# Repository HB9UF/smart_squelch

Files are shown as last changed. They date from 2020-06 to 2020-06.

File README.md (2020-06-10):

HB9UF Smart Squelch -- A squelch board with clever logic
========================================================

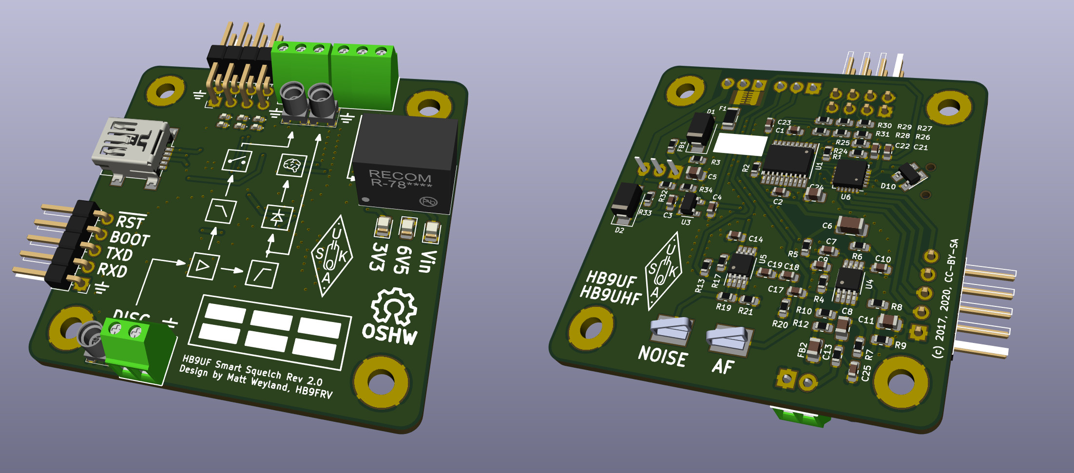
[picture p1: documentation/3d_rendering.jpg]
3D Rendering


A typical FM squelch for voice operation quantifies the amount of noise at frequencies above the voice frequency content and opens if said noise energy is sufficiently low. This works because without any input RF signal present, the FM detector produces wideband noise, reaching frequencies of several dozen kHz. A sufficiently strong RF input reduces that noise, the modulation emerges between typically 0 and 3 kHz and similarly, the noise above 3 kHz is reduced. Traditionally, a high-pass filter (HPF) attenuates the modulation while retaining the noise energy, and a subsequent peak-detector quantifies the amount of energy present, and finally a comparator circuit uses the peak detector output voltage to actuate the squelch.

Our squelch circuit is different. First, we use a microcontroller for the squelch logic. This allows us not only to change squelch thresholds without hardware access, but we can also implement more sophisticated squelching logic. For example, we can implement a hard threshold that is used when strong stations key off: The squelch is closed immediately, minimizing the squelch crash that is nothing but the manifestation of discriminator noise during the time-window after key-off and the closing of the squelch. At the same time, we can implement a second threshold for weak stations, e.g. stations far away, with low RF power, fading stations, or mobile stations with picket-fencing. Such stations may overcome the weak, but not the strong threshold. In this case, the squelch remains open for a predetermined time-window (e.g. 1 second) in order not to cut off the weak station. Note that this is superior to simply adding hysteresis to the aforementioned comparator, and that this is mimicking the behaviour of the [MICOR Squelch](http://www.repeater-builder.com/micor/micor-bi-level-squelch-theory.html) system.

The board also contains a number of extra circuitry such as an anti-aliasing low pass filter, a DC/DC converter etc. for integration with our repeater controller. This project is fully open source, the hardware is released under the CC-BY-SA license and the firmware is released under the GPL 2 license. Instructions for compiling and flashing the firmware are documented in a `README` file in the `firmware` subdirectory. The necessary tools and frameworks (ChibiOS and stm32flash) are also included there as git submodules. The circuitry was developed to improve the poor squelch performance of the Yaesu DR-1X repeater and is also successfully used in a number of homebrew 1.3 GHz repeaters.

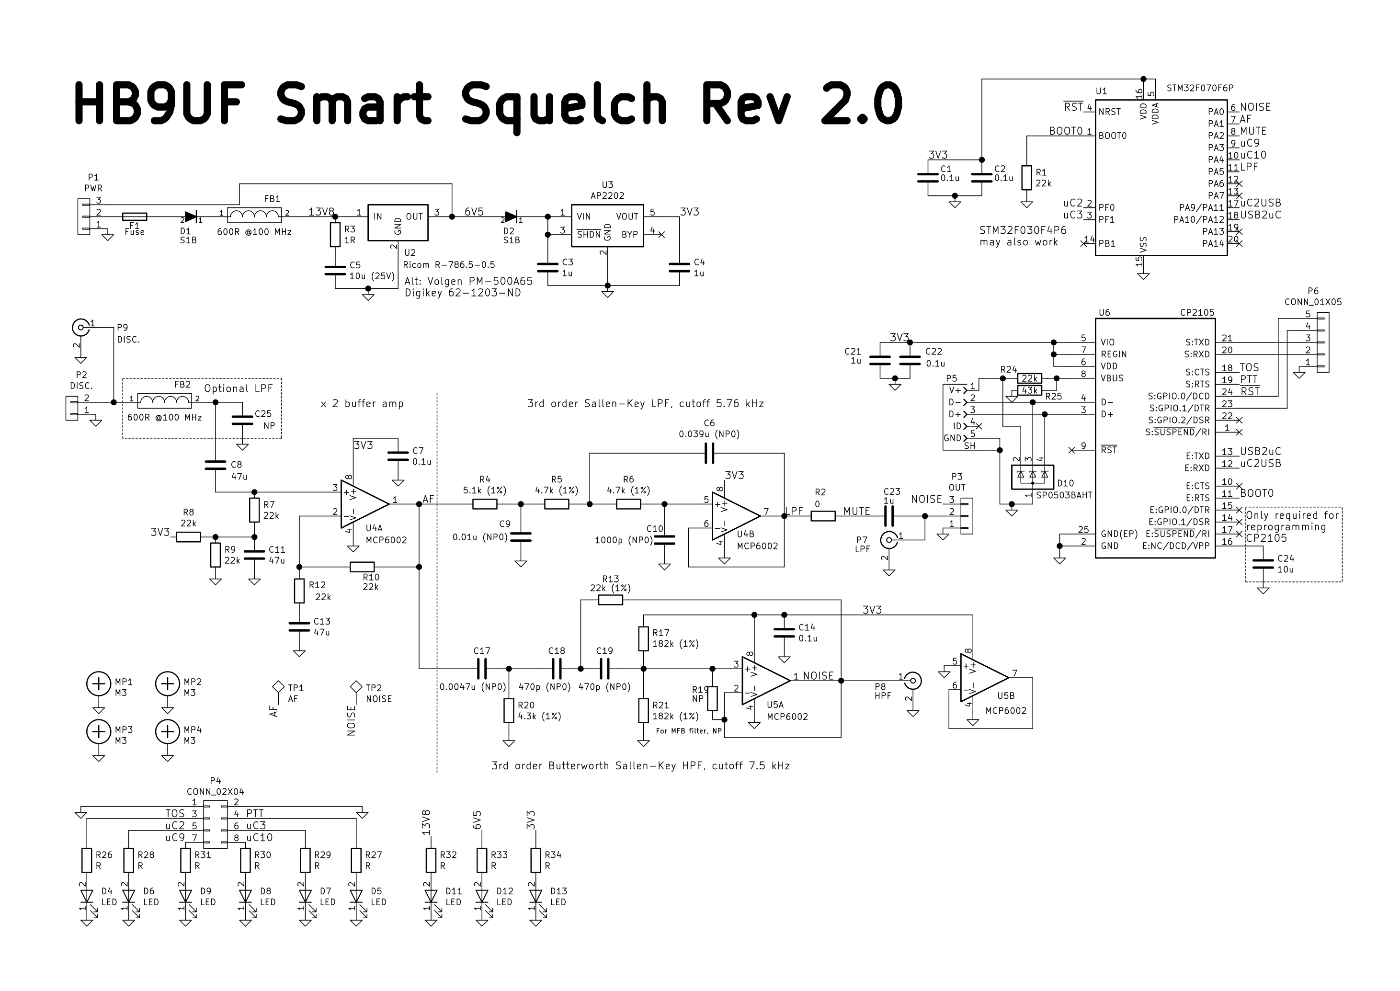
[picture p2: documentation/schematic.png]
Schematic


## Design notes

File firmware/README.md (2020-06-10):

Compiling
=========

This is how to compile the firmware on linux:

1. Check out the ChibiOS submodule by running `git submodule update --init`. Alternatively, modify the Makefile to point to your existing ChibiOS root.
2. Run the `make`command.
3. Firmware is available in the `build` subdirectory.

Programming
===========

The STM32 microcontroller can be flashed from USB using the 'stm32flash-code' tool. The microcontroller needs to boot into the bootloader for this to work. Follow these steps in order to achieve this:

1. Activate the GPIO capabilities of the CP2105 USB bridge: `echo 355 > /sys/class/gpio/export`. The Number (355) may vary on your system.
2. Reset the microcontroller. The BOOT0 pin is high by default, starting the bootloader in reset:
```
echo 0 > /sys/class/gpio/gpio355/value
sleep 0.1
echo 1 > /sys/class/gpio/gpio355/value
```
3. Flash the firmware: `stm32flash -w build/ch.hex /dev/ttyUSB0`
4. Pull the BOOT0 pin low. The pin is connected to the RTS. Helper program rts.py keeps the pin low for 10 seconds. Thus, running `python rts.py &` fulfils this step. The subsequent reset in the next step must take place within 10 secods.
5. Reset the microontroller once again:
```
echo 0 > /sys/class/gpio/gpio355/value
sleep 0.1
echo 1 > /sys/class/gpio/gpio355/value
```

Alternatively, `stm32flash` can be alled with the appropriate entry and exit sequences:

```
stm32flash-code/stm32flash -w ../firmware/build/ch.hex /dev/ttyUSB0 -i '-rts,-355,355,,,:rts,-355,355'
```

Note that this still requires activation of the P2105 GPIO capabilities and the GPIO number (355) is subject to change.

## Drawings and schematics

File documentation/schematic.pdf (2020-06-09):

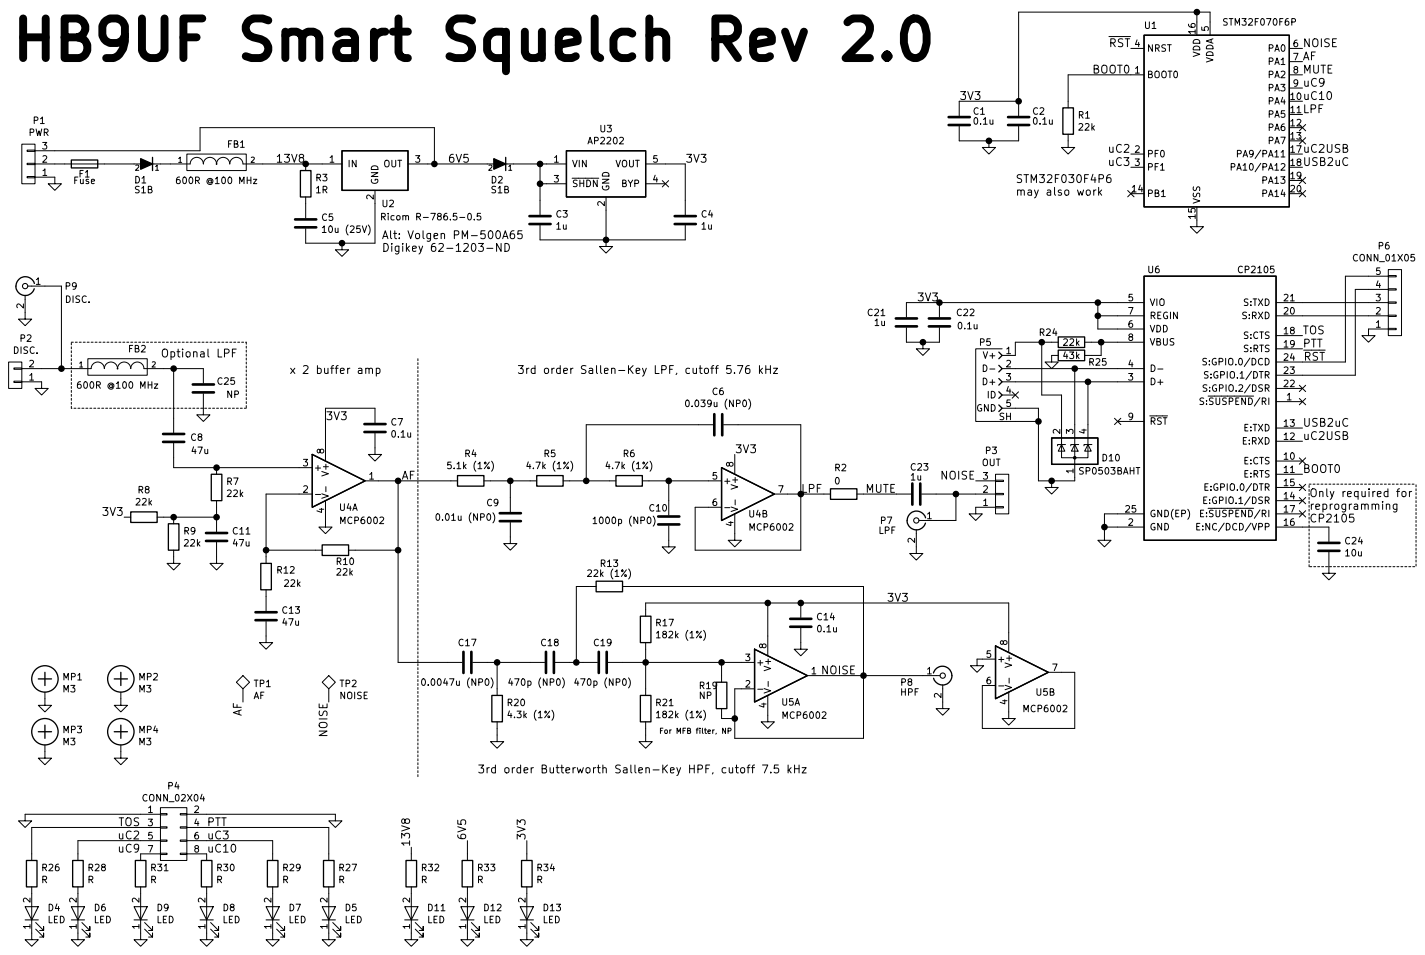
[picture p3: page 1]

may also work Todo: - output divider

For MFB filter, NP HB9UF Smart Squelch Rev 2.0

3rd order Butterworth Sallen-Key HPF, cutoff 7.5 kHz

TOS 3 | 4 PTT
uC2 5 | uC3 6

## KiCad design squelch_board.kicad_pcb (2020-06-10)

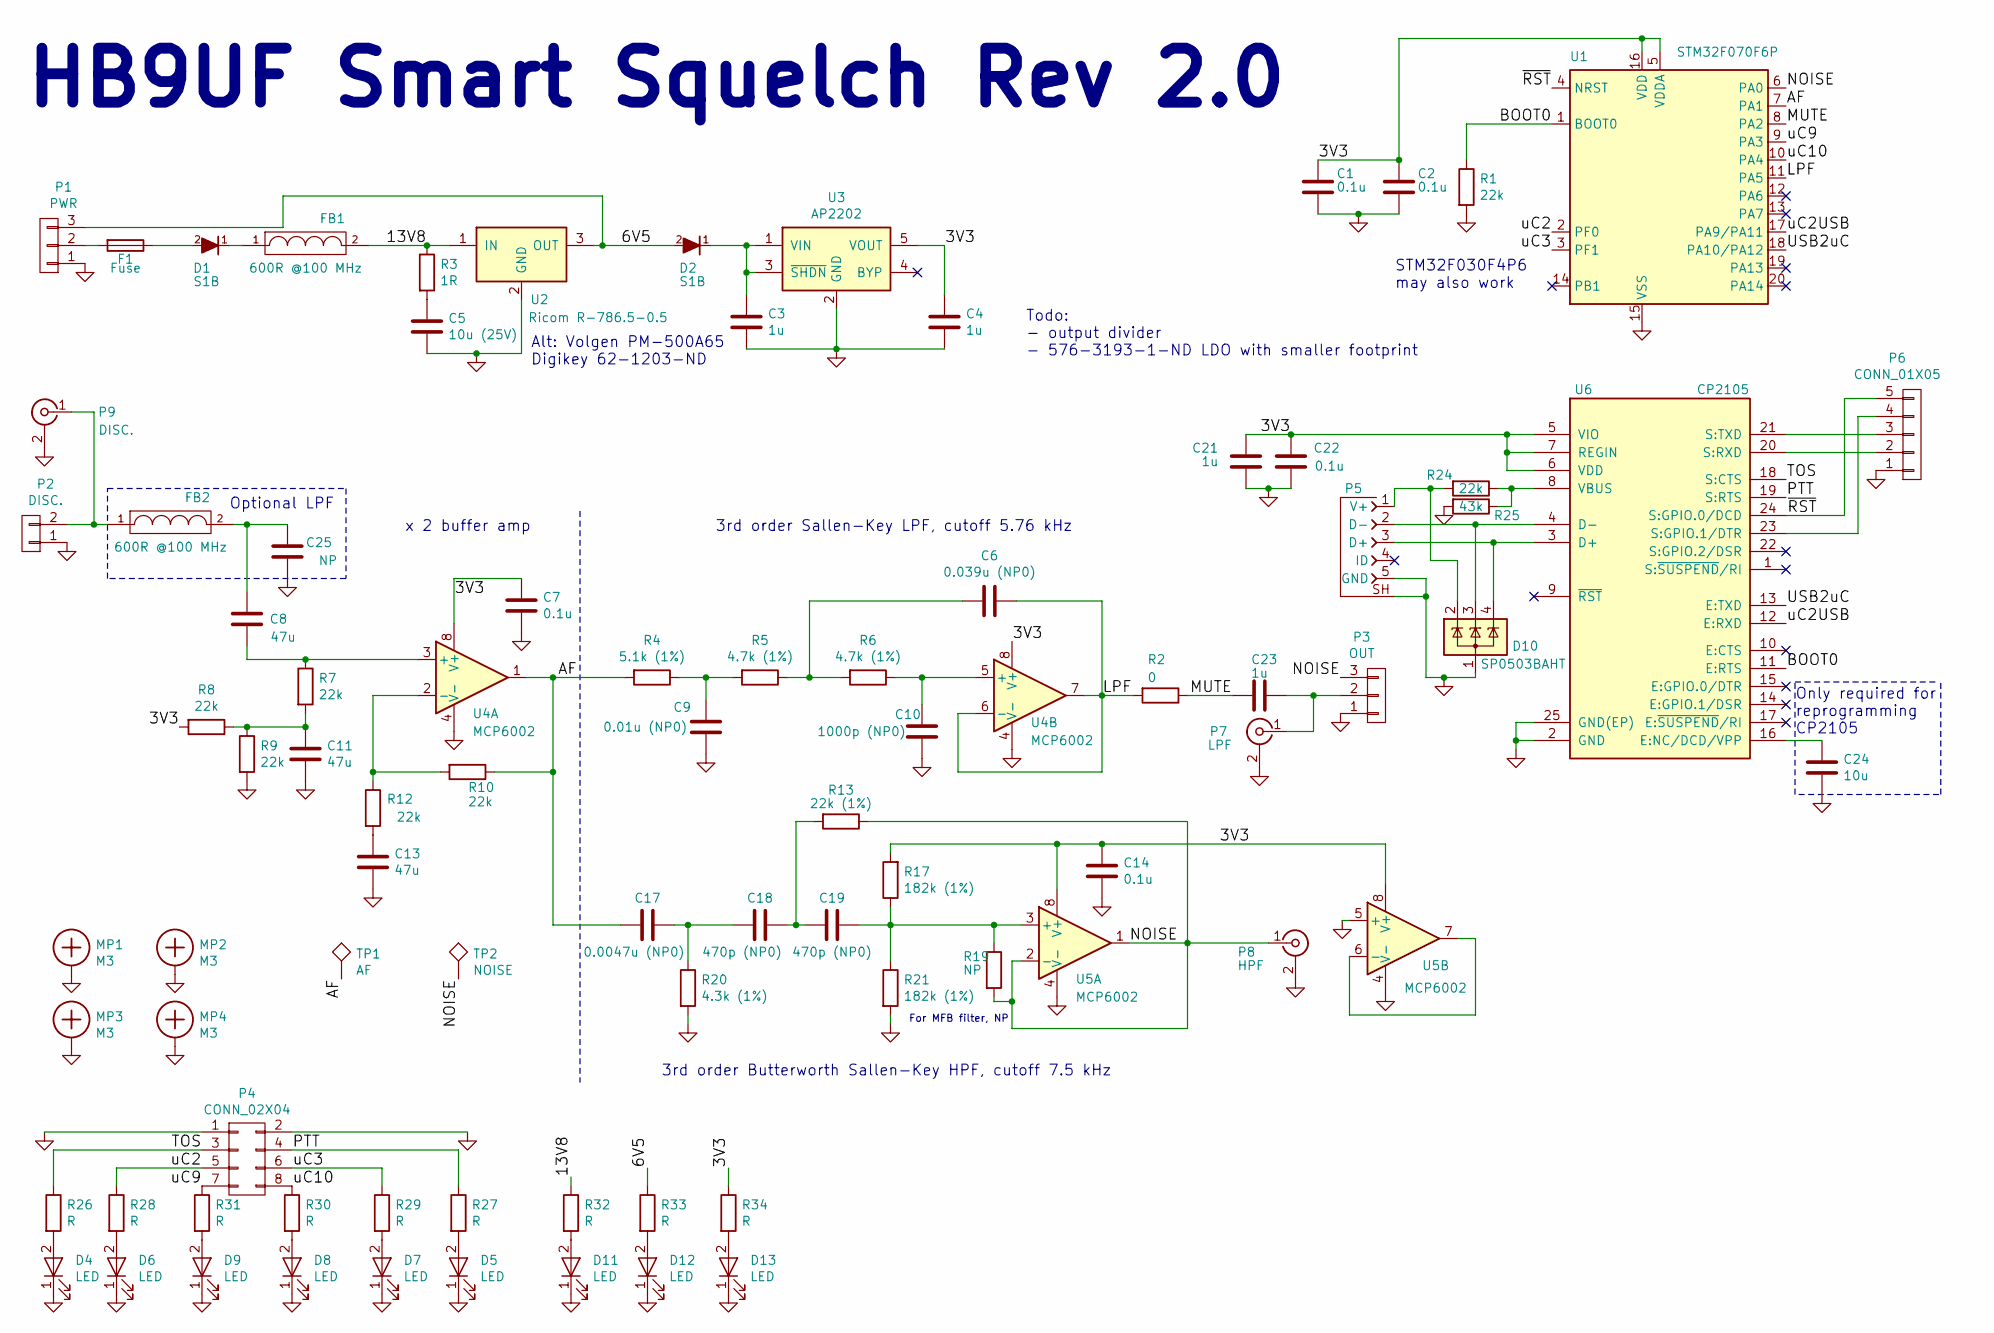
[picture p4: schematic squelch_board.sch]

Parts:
C1, C2, C7, C14, C22: 0.1u; C_0603_1608Metric
C3, C4, C21, C23: 1u; C_0603_1608Metric
C5: 10u (25V); C_0805_2012Metric
C6: 0.039u (NP0); C_1206_3216Metric
C8, C11, C13: 47u; C_0805_2012Metric
C9: 0.01u (NP0); C_0603_1608Metric
C10: 1000p (NP0); C_0603_1608Metric
C17: 0.0047u (NP0); C_0603_1608Metric
C18, C19: 470p (NP0); C_0603_1608Metric
C24: 10u; C_0805_2012Metric
C25: NP; C_0603_1608Metric
D1, D2: S1B; D_SMA
D4, D5, D6, D7, D8, D9: LED; LED_0402_1005Metric
D10: SP0503BAHT; SOT-143
D11, D12, D13: LED; LED_0805_2012Metric
F1: Fuse; R_1206_3216Metric
FB1, FB2: 600R @100 MHz; R_0603_1608Metric
MP1, MP2, MP3, MP4: M3; MountingHole_3mm_Pad
P1: PWR; mpt_0,5%2f3-2,54
P2: DISC.; mpt_0,5%2f2-2,54
P3: OUT; mpt_0,5%2f3-2,54
P4: CONN_02X04; PinHeader_2x04_P2.54mm_Horizontal
P5: CONN-10033526-N3212LF; USB_Mini-B_Lumberg_2486_01_Horizontal
P6: CONN_01X05; PinHeader_1x05_P2.54mm_Horizontal
P7: LPF; MOLEX-0734152063
P8: HPF; MOLEX-0734152063
P9: DISC.; MOLEX-0734152063
R1, R7, R8, R9, R10, R12, R24: 22k; R_0603_1608Metric
R2: 0; R_0603_1608Metric
R3: 1R; R_0603_1608Metric
R4: 5.1k (1%); R_0603_1608Metric
R5, R6: 4.7k (1%); R_0603_1608Metric
R13: 22k (1%); R_0603_1608Metric
R17, R21: 182k (1%); R_0603_1608Metric
R19: NP; R_0603_1608Metric
R20: 4.3k (1%); R_0603_1608Metric
R25: 43k; R_0603_1608Metric
R26, R27, R28, R29, R30, R31, R32, R33, R34: R; R_0603_1608Metric
TP1: AF; TESTPOINT-KEYSTONE-5018
TP2: NOISE; TESTPOINT-KEYSTONE-5018
U1: STM32F070F6P; TSSOP-20_4.4x6.5mm_P0.65mm
U2: Ricom R-786.5-0.5; R-78xx-0.5
U3: AP2202; SOT-23-5
U4, U5: MCP6002; MSOP-8_3x3mm_P0.65mm
U6: CP2105; QFN-24-1EP_4x4mm_P0.5mm_EP2.7x2.7mm

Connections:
/3V3: C1.1, C2.1, C4.1, C7.1, C14.1, C21.1, C22.1, R8.2, R17.2, R34.1, U1.5 (VDDA), U1.16 (VDD), U3.5 (VOUT), U4.8 (V+), U5.8 (V+), U6.5 (VIO), U6.6 (VDD), U6.7 (REGIN)
/6V5: D2.2 (A), P1.3, R33.1, U2.3 (OUT)
/13V8: FB1.2, R3.1, R32.1, U2.1 (IN)
/AF: C17.2, R4.2, R10.1, TP1.1, U1.7 (PA1), U4.1
/BOOT0: R1.1, U1.1 (BOOT0), U6.11 (E:RTS)
/LPF: C6.1, R2.2, U1.11 (PA5), U4.6 (-), U4.7
/MUTE: C23.2, R2.1, U1.8 (PA2)
/NOISE: P3.3, P8.1 (In), R13.1, R19.2, TP2.1, U1.6 (PA0), U5.1, U5.2 (-)
/PTT: P4.4, R27.1, U6.19 (S:RTS)
/TOS: P4.3, R26.1, U6.18 (S:CTS)
/USB2uC: U1.18 (PA10/PA12), U6.13 (E:TXD)
/uC2: P4.5, R28.1, U1.2 (PF0)
/uC2USB: U1.17 (PA9/PA11), U6.12 (E:RXD)
/uC3: P4.6, R29.1, U1.3 (PF1)
/uC9: P4.7, R31.1, U1.9 (PA3)
/uC10: P4.8, R30.1, U1.10 (PA4)
/~RST: P6.5, U1.4 (NRST), U6.24 (S:GPIO.0/DCD)
GND: C1.2, C2.2, C3.2, C4.2, C5.2, C7.2, C9.2, C10.2, C11.2, C13.2, C14.2, C21.2, C22.2, C24.2, C25.1, D4.1 (K), D5.1 (K), D6.1 (K), D7.1 (K), D8.1 (K), D9.1 (K), D10.1 (A), D11.1 (K), D12.1 (K), D13.1 (K), MP1.1, MP2.1, MP3.1, MP4.1, P1.1, P2.1, P3.1, P4.1, P4.2, P5.5 (GND), P5.SH (SHIELD), P6.1, P7.2 (Ext), P8.2 (Ext), P9.2 (Ext), R1.2, R9.2, R20.2, R21.2, R25.2, U1.15 (VSS), U2.2 (GND), U3.2 (GND), U4.4 (V-), U5.4 (V-), U5.5 (+), U6.2 (GND), U6.25 (GND(EP))
unnamed: C3.1, D2.1 (K), U3.1 (VIN), U3.3 (~SHDN~)
unnamed: C5.1, R3.2
unnamed: C6.2, R5.1, R6.2
unnamed: C8.1, R7.1, U4.3 (+)
unnamed: C9.1, R4.1, R5.2
unnamed: C10.1, R6.1, U4.5 (+)
unnamed: C11.1, R7.2, R8.1, R9.1
unnamed: C13.1, R12.2
unnamed: C17.1, C18.2, R20.1
unnamed: C18.1, C19.2, R13.2
unnamed: C19.1, R17.1, R19.1, R21.1, U5.3 (+)
unnamed: C23.1, P3.2, P7.1 (In)
unnamed: C24.1, U6.16 (E:NC/DCD/VPP)
unnamed: C8.2, C25.2, FB2.2
unnamed: D1.1 (K), FB1.1
unnamed: D1.2 (A), F1.1
unnamed: D4.2 (A), R26.2
unnamed: D5.2 (A), R27.2
unnamed: D6.2 (A), R28.2
unnamed: D7.2 (A), R29.2
unnamed: D8.2 (A), R30.2
unnamed: D9.2 (A), R31.2
unnamed: D10.2 (K), P5.1 (V+), R24.2
unnamed: D10.3 (K), P5.2 (D-), U6.4 (D-)
unnamed: D10.4 (K), P5.3 (D+), U6.3 (D+)
unnamed: D11.2 (A), R32.2
unnamed: D12.2 (A), R33.2
unnamed: D13.2 (A), R34.2
unnamed: F1.2, P1.2
unnamed: FB2.1, P2.2, P9.1 (In)
unnamed: P6.2, U6.20 (S:RXD)
unnamed: P6.3, U6.21 (S:TXD)
unnamed: P6.4, U6.23 (S:GPIO.1/DTR)
unnamed: R10.2, R12.1, U4.2 (-)
unnamed: R24.1, R25.1, U6.8 (VBUS)
unnamed: U5.6 (-), U5.7

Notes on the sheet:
x 2 buffer amp
3rd order Sallen-Key LPF, cutoff 5.76 kHz
3rd order Butterworth Sallen-Key HPF, cutoff 7.5 kHz
HB9UF Smart Squelch Rev 2.0
For MFB filter, NP
Alt: Volgen PM-500A65 Digikey 62-1203-ND
Only required for reprogramming CP2105
STM32F030F4P6 may also work
Optional LPF
Todo: - output divider - 576-3193-1-ND LDO with smaller footprint

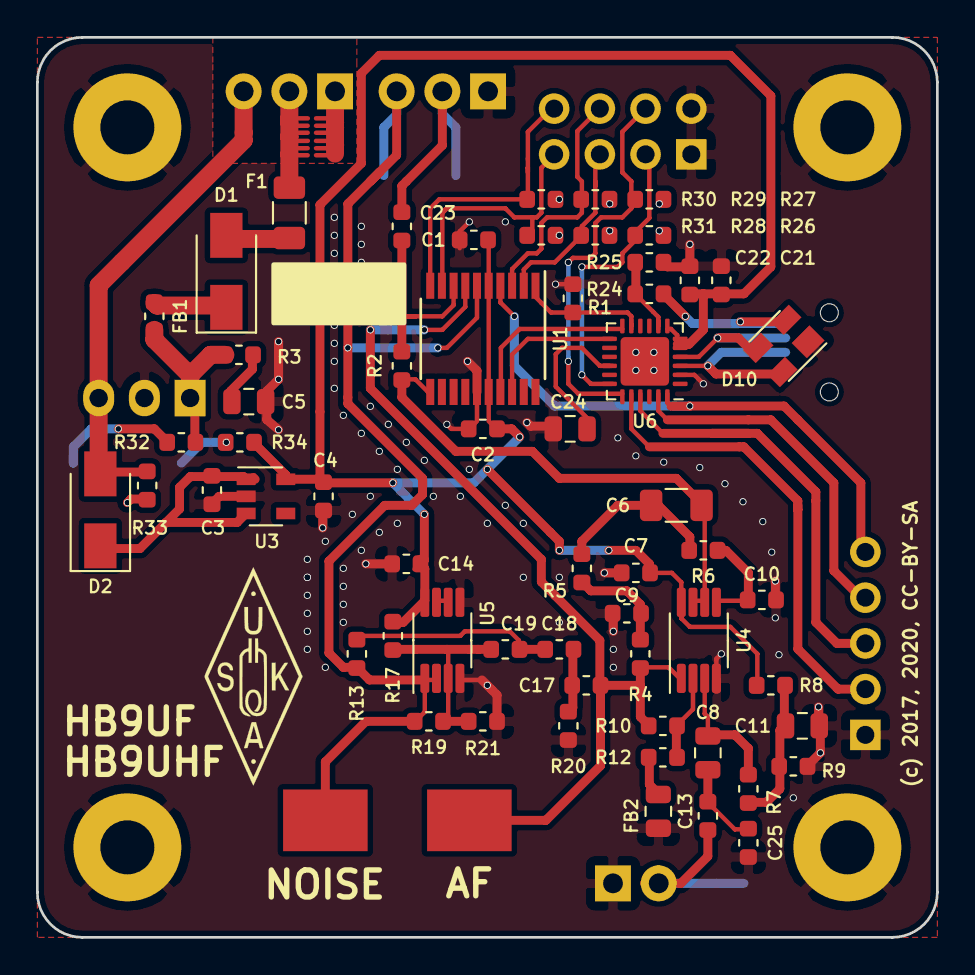
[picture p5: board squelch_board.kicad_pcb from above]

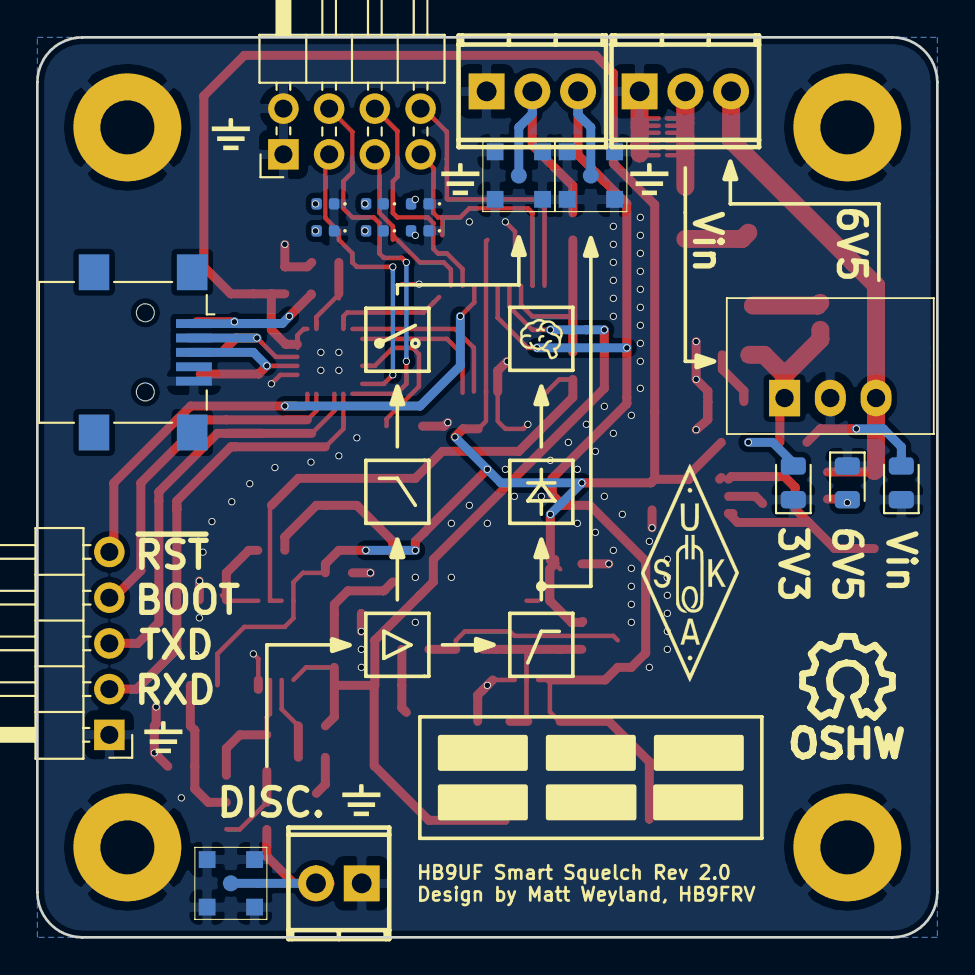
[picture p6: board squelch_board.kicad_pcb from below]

Board: 2 copper layers, 50.0 x 50.0 mm, 90 parts (25 on the bottom side), 54 nets.

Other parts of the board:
SYM: Symbol_OSHW-Logo_SilkScreen_07Jul2012; Symbol_OSHW-Logo_SilkScreen
VAL: GND
VAL#2, VAL#3, VAL#4, VAL#5: GND

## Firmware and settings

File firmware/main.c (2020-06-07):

/* HB9UF smart squelch in a nutshell:
 *
 * The microcontroller samples ADC channel 0 at a rate of 50 kHz. This pin is
 * expected to be fed with a buffered (i.e. low impedance) discriminator tap
 * output from which audio frequencies are removed. Typiclly, this is achieved
 * with a HPF where frequencies below ~3 kHz are attenuated strongly.
 *
 * The samples are stored in a buffer. When the buffer is half full, the energy
 * of the samples is calculated and accumulated. Once every 8 iterations
 * (i.e. roughly 10 times per second), the accumulator is used for squelching.
 * Finally, the accumulator is reset for the next cycle. A backlog of accmulator
 * values is kept in a circular buffer.
 *
 * Squelch logic is as follows (accumulator =a, "mean" in the code):
 * 1. Squelch is opened if a < WEAK_THRESHOLD
 * 2. Squelch is immediately closed if a > WEAK_THRESHOLD and the backlog cotains
 *    values < STRONG_THRESHOLD without exception.
 * 3. Squelch remains open as long as the backlog contains at least one value
 *    below WEAK_THRESHOLD (grace tail).
 *
 *  This methodology eliminates the squelch crash for quieting stations, while
 *  weak stations, fading stations and statios with picket-fencing are not
 *  artifically impaired by our own squelching action.
 */

#include "ch.h"
#include "hal.h"
#include "chprintf.h"

#include "io.h"
#include "backlog.h"
#include "adc_gpt.h"
#include "uart.h"

// FIXME: make this configurable
const uint32_t WEAK_THRESHOLD = 38000;
const uint32_t STRONG_THRESHOLD = 7000;

int main(void)
{
    halInit();
    chSysInit();
    io_init();
    uart_init();
    adc_init();

    circular_buf_t backlog;
    circular_buf_init(&backlog);

    bool squelch_open = false;
    bool squelch_armed = false;
    uint32_t mean = 0;
    uint8_t counter = 0;
    char squelch_flag = ' ';
    while (true)
    {
        chBSemWait(&wait_for_sample);
        // palClearPad(GPIOA, 4); // Use this to check how much idle time we have per cycle
        uint32_t sum = 0;
        for(adcsample_t *s = first_sample; s < last_sample; s++)
        {
            int16_t tmp = (int16_t) *s;
            sum += (tmp-2047)*(tmp-2047);
        }
        mean += sum/8;
        if(++counter == 8)
        {
            // We hit this condition approx. 12 times per second
            mean /= 1000; // Divide by 1000 to get numbers that are easier to handle
            bool opening_squelch = false;
            if(squelch_open && mean > WEAK_THRESHOLD)
            {
                if(circular_buf_all_lower_than(&backlog, STRONG_THRESHOLD))
                {
                    // Immediately close squelch
                    io_close_squelch();
                    squelch_open = false;
                    squelch_flag = ' ';
                }
                else if(circular_buf_any_lower_than(&backlog, WEAK_THRESHOLD))
                {
                    // Don't close squelch just yet, enter grace tail instead.
                    squelch_flag = '?';
                }
                else
                {
                    // Close squelch afer grace tail
                    io_close_squelch();
                    squelch_open = false;
                    squelch_flag = ' ';
                }
            }
            else if(squelch_open && mean < WEAK_THRESHOLD)
            {
                // Set correct flag (otherwise the flag remains '?')
                squelch_flag = '*';
            }
            else if(!squelch_open && !squelch_armed && mean < WEAK_THRESHOLD)
            {
                // Arm squelch
                squelch_armed = true;
                squelch_flag = 'A';
            }
            else if(!squelch_open && squelch_armed && mean > WEAK_THRESHOLD)
            {
                // Disarm squelch
                squelch_armed = false;
                squelch_flag = ' ';
            }
            else if(!squelch_open && squelch_armed && mean < WEAK_THRESHOLD)
            {
                // Open squelch
                io_open_squelch();
                circular_buf_reset(&backlog, 0);
                squelch_open = true;
                opening_squelch = true;
                squelch_armed = false;
                squelch_flag = '*';
            }
            if(!opening_squelch)
            {
                // We only add this to the backlog if we are sure that PTT was asserted for the full duration
                // of the acquisition. Otherwise, the mean may be too low and trigger the grace tail.
                circular_buf_append(&backlog, mean);
            }
            chprintf((BaseSequentialStream*)&SD1, "%c %c %d\r\n", squelch_open ? '!' : ' ', squelch_flag, mean);
            mean = 0;
            counter = 0;
        }
        // palSetPad(GPIOA, 4); // See comment above

    }
}

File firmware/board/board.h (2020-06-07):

/*
    ChibiOS - Copyright (C) 2006..2015 Giovanni Di Sirio

    Licensed under the Apache License, Version 2.0 (the "License");
    you may not use this file except in compliance with the License.
    You may obtain a copy of the License at

        http://www.apache.org/licenses/LICENSE-2.0

    Unless required by applicable law or agreed to in writing, software
    distributed under the License is distributed on an "AS IS" BASIS,
    WITHOUT WARRANTIES OR CONDITIONS OF ANY KIND, either express or implied.
    See the License for the specific language governing permissions and
    limitations under the License.
*/

#ifndef _BOARD_H_
#define _BOARD_H_

/*
 * Setup for STMicroelectronics NUCLEO-F030R8 board.
 */

/*
 * Board identifier.
 */
#define BOARD_ST_NUCLEO_F030R8
#define BOARD_NAME                  "STMicroelectronics NUCLEO-F030R8"

/*
 * Board oscillators-related settings.
 * NOTE: LSE not fitted.
 * NOTE: HSE not fitted.
 */
#if !defined(STM32_LSECLK)
#define STM32_LSECLK                0U
#endif

#define STM32_LSEDRV                (3U << 3U)

#if !defined(STM32_HSECLK)
#define STM32_HSECLK                0U
#endif

#define STM32_HSE_BYPASS

/*
 * MCU type as defined in the ST header.
 */
#define STM32F030x6

/*
 * IO pins assignments.
 */
#define GPIOA_PIN0                  0U
#define GPIOA_PIN1                  1U
#define GPIOA_USART_TX              2U
#define GPIOA_USART_RX              3U
#define GPIOA_PIN4                  4U
#define GPIOA_LED_GREEN             5U
#define GPIOA_PIN6                  6U
#define GPIOA_PIN7                  7U
#define GPIOA_PIN8                  8U
#define GPIOA_PIN9                  9U
#define GPIOA_PIN10                 10U
#define GPIOA_OTG_FS_DM             11U
#define GPIOA_OTG_FS_DP             12U
#define GPIOA_SWDIO                 13U
#define GPIOA_SWCLK                 14U
#define GPIOA_PIN15                 15U

#define GPIOB_PIN0                  0U
#define GPIOB_PIN1                  1U
#define GPIOB_PIN2                  2U
#define GPIOB_SWO                   3U
#define GPIOB_PIN4                  4U
#define GPIOB_PIN5                  5U
#define GPIOB_PIN6                  6U
#define GPIOB_PIN7                  7U
#define GPIOB_PIN8                  8U
#define GPIOB_PIN9                  9U
#define GPIOB_PIN10                 10U
#define GPIOB_PIN11                 11U
#define GPIOB_PIN12                 12U
#define GPIOB_PIN13                 13U
#define GPIOB_PIN14                 14U
#define GPIOB_PIN15                 15U

#define GPIOC_PIN0                  0U
#define GPIOC_PIN1                  1U
#define GPIOC_PIN2                  2U
#define GPIOC_PIN3                  3U
#define GPIOC_PIN4                  4U
#define GPIOC_PIN5                  5U
#define GPIOC_PIN6                  6U
#define GPIOC_PIN7                  7U
#define GPIOC_PIN8                  8U
#define GPIOC_PIN9                  9U
#define GPIOC_PIN10                 10U
#define GPIOC_PIN11                 11U
#define GPIOC_PIN12                 12U
#define GPIOC_BUTTON                13U
#define GPIOC_PIN14                 14U
#define GPIOC_PIN15                 15U

#define GPIOD_PIN0                  0U
#define GPIOD_PIN1                  1U
#define GPIOD_PIN2                  2U
#define GPIOD_PIN3                  3U
#define GPIOD_PIN4                  4U
#define GPIOD_PIN5                  5U
#define GPIOD_PIN6                  6U
#define GPIOD_PIN7                  7U
#define GPIOD_PIN8                  8U
#define GPIOD_PIN9                  9U
#define GPIOD_PIN10                 10U
#define GPIOD_PIN11                 11U
#define GPIOD_PIN12                 12U
#define GPIOD_PIN13                 13U
#define GPIOD_PIN14                 14U
#define GPIOD_PIN15                 15U

#define GPIOF_OSC_IN                0U
#define GPIOF_OSC_OUT               1U
#define GPIOF_PIN2                  2U
#define GPIOF_PIN3                  3U
#define GPIOF_PIN4                  4U
#define GPIOF_PIN5                  5U
#define GPIOF_PIN6                  6U
#define GPIOF_PIN7                  7U
#define GPIOF_PIN8                  8U
#define GPIOF_PIN9                  9U
#define GPIOF_PIN10                 10U
#define GPIOF_PIN11                 11U
#define GPIOF_PIN12                 12U
#define GPIOF_PIN13                 13U
#define GPIOF_PIN14                 14U
#define GPIOF_PIN15                 15U
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

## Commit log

2020-06-07 Adding .gitignore file for KiCad
2020-06-07 Initial commit of board files
    [squelch_board.kicad_pcb, squelch_board.sch]
2020-06-07 Upgrading schematic to current version of KiCad
    [squelch_board.sch]
2020-06-07 Adding missing KiCad files.
2020-06-07 Adding KiCad backup directory to .gitignore file
2020-06-07 Adding linker file for STM32F070
2020-06-07 Alter Makefile to compile for STM32F070 target (was: STM32F030)
2020-06-07 Actuating squelch pin GPIOF1.
2020-06-07 Moving ADC-related code to dedicated adc module (adc.{c,h})
2020-06-07 Moving UART-related code to uart module (uart.{c,h})
2020-06-07 Reducing sampling time (since we can, the S&H circuit is driven by OPA)
2020-06-08 Starting with rev 2.0 mods: Removing detector circuitry
    [squelch_board.kicad_pcb, squelch_board.sch]
2020-06-08 Removing R23 (selector for OPA rail voltage and potential ripple rejection)
    [squelch_board.kicad_pcb, squelch_board.sch]
2020-06-08 Adding fencing vias around AF_BUF track
    [squelch_board.kicad_pcb]
2020-06-08 Slight modification to avoid overlapping country-yard errors.
    [squelch_board.kicad_pcb]
2020-06-08 Re-aligning silk labels to prevent them from overlapping.
    [squelch_board.kicad_pcb]
2020-06-08 Renaming "HPF" to "NOISE" in schematic and on silk screen.
    [squelch_board.kicad_pcb, squelch_board.sch]
2020-06-08 Swapping out STM32F030F4P6 for STM32F070F6P
    [squelch_board.kicad_pcb, squelch_board.sch]
2020-06-08 Slight rearrangement of schematic, renaming nodes for consistency.
    [squelch_board.kicad_pcb, squelch_board.sch]
2020-06-08 Bumping version number to 2.0
    [squelch_board.kicad_pcb, squelch_board.sch]
2020-06-08 Swapping out footprints for current ones in order to have 3d models
    [squelch_board.kicad_pcb, squelch_board.sch]
2020-06-08 Adding HB9UF artwork on backside of PCB
    [squelch_board.kicad_pcb]
2020-06-08 Moving testpoints to board edge
    [squelch_board.kicad_pcb]
2020-06-08 Slight reduction of white silk square for fuse rating
    [squelch_board.kicad_pcb]
2020-06-08 Configuring 3d model for testpoint
    [squelch_board.kicad_pcb]
2020-06-08 Hiding USB connector reference designator
    [squelch_board.kicad_pcb]
2020-06-09 Changing silk screen block diagram: brin pictogram
    Brain pictogrm is licensed under a CC-BY license, jessie_vp is
    attributed for the original work. Source:
    https://thenounproject.com/term/brain/35201/
    [squelch_board.kicad_pcb]
2020-06-09 Adding note to schematic about optional input LPF
    [squelch_board.sch]
2020-06-09 Renaming "Squelch Board" to "HB9UF Smart Squelch"
    [squelch_board.kicad_pcb, squelch_board.sch]
2020-06-09 Adding README file, schematics and 3d rendering of project.
2020-06-09 Adding PDF version of schematic.
2020-06-10 Fixing direction of power supply arrows on silk screen
    [squelch_board.kicad_pcb]
2020-06-10 Minor rearrangement of resistor designator
    [squelch_board.kicad_pcb]

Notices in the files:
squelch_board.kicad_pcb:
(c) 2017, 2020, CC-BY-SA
